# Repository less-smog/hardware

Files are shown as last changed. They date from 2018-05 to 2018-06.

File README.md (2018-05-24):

# IMPORTANT NOTE

The current revision (rev2) is undergoing tests - it's best to wait until the hardware has been well-tested before ordering PCBs and such.

# Open Hardware Air Pollution sensor

## housing
KRADEX Z56JPH housing is selected. Drawings and  3D models are available at [manufacturers site](https://www.kradex.com.pl/shop?product=z56).

## 3D model
Models from KiCad 4.0.7 release are used where available. Other models are in \lib\packages3d\ directory. You must copy them to KiCad KISYS3DMOD directory (i.e. C:\Program Files\KiCad\share\kicad\modules\packages3d on Windows). These models are:

* ESP-12E by [Jerry Dunmire (jdunmire)](https://github.com/jdunmire/kicad-ESP8266) (under Creative Commons Attribution-ShareAlike 4.0 International License)
* Molex 530470810, 530480810, 1050170001 by [Molex](https://www.molex.com/)
* MicroswitchSmd_4.3 by [Würth Elektronik](http://katalog.we-online.com/en/em/TASV_6X6_SMD?sid=3e9e02d6c0)
* Other are custom made

## LICENSE

This design has been released under the CERN Open Hardware Licence v1.2. We require that you notify us when you undertake either mass-production
of this design, or incorporate this design into an existing product, by e-mailing us at product@less-smog.org

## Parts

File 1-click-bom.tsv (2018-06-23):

References | Qty | Description
C1, C3 | 2 | C N.C. 0805 M
C6, C7, C8 | 3 | C 100nF 0603 M
C2, C3, C5, C9 | 4 | C 10uF/10V 0805 M
CON1 | 1 | USB OTG Micro Micro-B Molex-105017-0001
CON2 | 1 | Conn 01x05 PROG Pin Header Straight 1x05 Pitch2.54mm
CON3 | 1 | Jack-DC N.C. BARREL JACK
CON4 | 1 | Conn 01x04 HTU21D module
CON5 | 1 | Conn 01x08 PMS3003/5003 Molex PicoBlade 53048-0810
CON6 | 1 | Conn 01x07 AUX E45-TTL-1W
CON7 | 1 | Conn 01x05 SDS011 B5B-XH-A(LF)(SN)
D1, D2, D3, D4, D5, D6, D7, D8, D9, D10 | 10 | LED RABG RGB 5mm D5.0mm-4
Q1, Q2, Q3 | 3 | Q NMOS GSD BSS214N SOT-23
R9, R11, R12, R14 | 4 | R N.C. 0603 M
R39, R41 | 2 | R 10k 0603 M
RN1, RN2, RN3, RN4, RN5, RN6, RN7, RN8, RN9, RN10 | 10 | R Network 4 150R 4x0603 M
RN11, RN12 | 2 | R Network 4 10k 4x0603 M
SW1 | 1 | SW Push RESET MicroswitchSmd-4.3 N
SW2 | 1 | SW Push CFG MicroswitchSmd-4.3 N
TP1 | 1 | TEST 1P ESP PD TP 1.0 0.5 THT
TP2, TP14 | 2 | TEST 1P GND TP 1.7 1.0 THT
TP4 | 1 | TEST 1P CFG TP 1.7 1.0 THT
TP5 | 1 | TEST 1P RESET TP 1.7 1.0 THT
TP8 | 1 | TEST 1P +5V TP 1.0 0.5 THT
TP9 | 1 | TEST 1P +12V TP 1.0 0.5 THT
TP3, TP6, TP7, TP10, TP11, TP12 | 6 | TEST 1P - TP 1.0 0.5 THT
TP13 | 1 | TEST 1P +3V3 TP 1.0 0.5 THT
U1 | 1 | LM7805 TO220 N.C. 5V DC
U2 | 1 | TLV1117-33 TLV1117LV33DCY SOT-223-3Lead TabPin2
U3 | 1 | ESP-12E ESP-12F
U4 | 1 | HTU21D
U5 | 1 | PMS7003 THT

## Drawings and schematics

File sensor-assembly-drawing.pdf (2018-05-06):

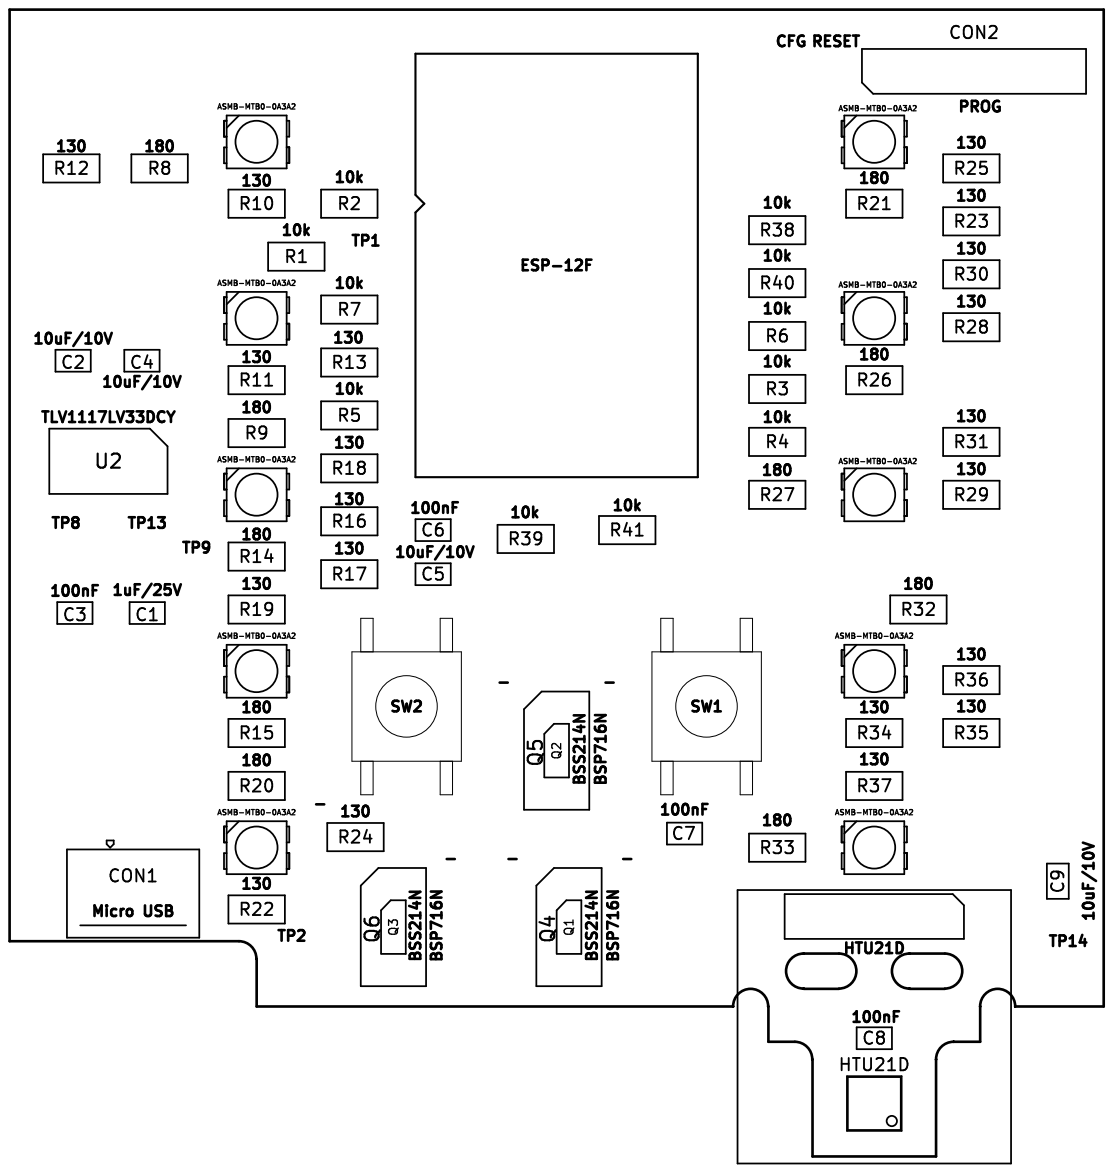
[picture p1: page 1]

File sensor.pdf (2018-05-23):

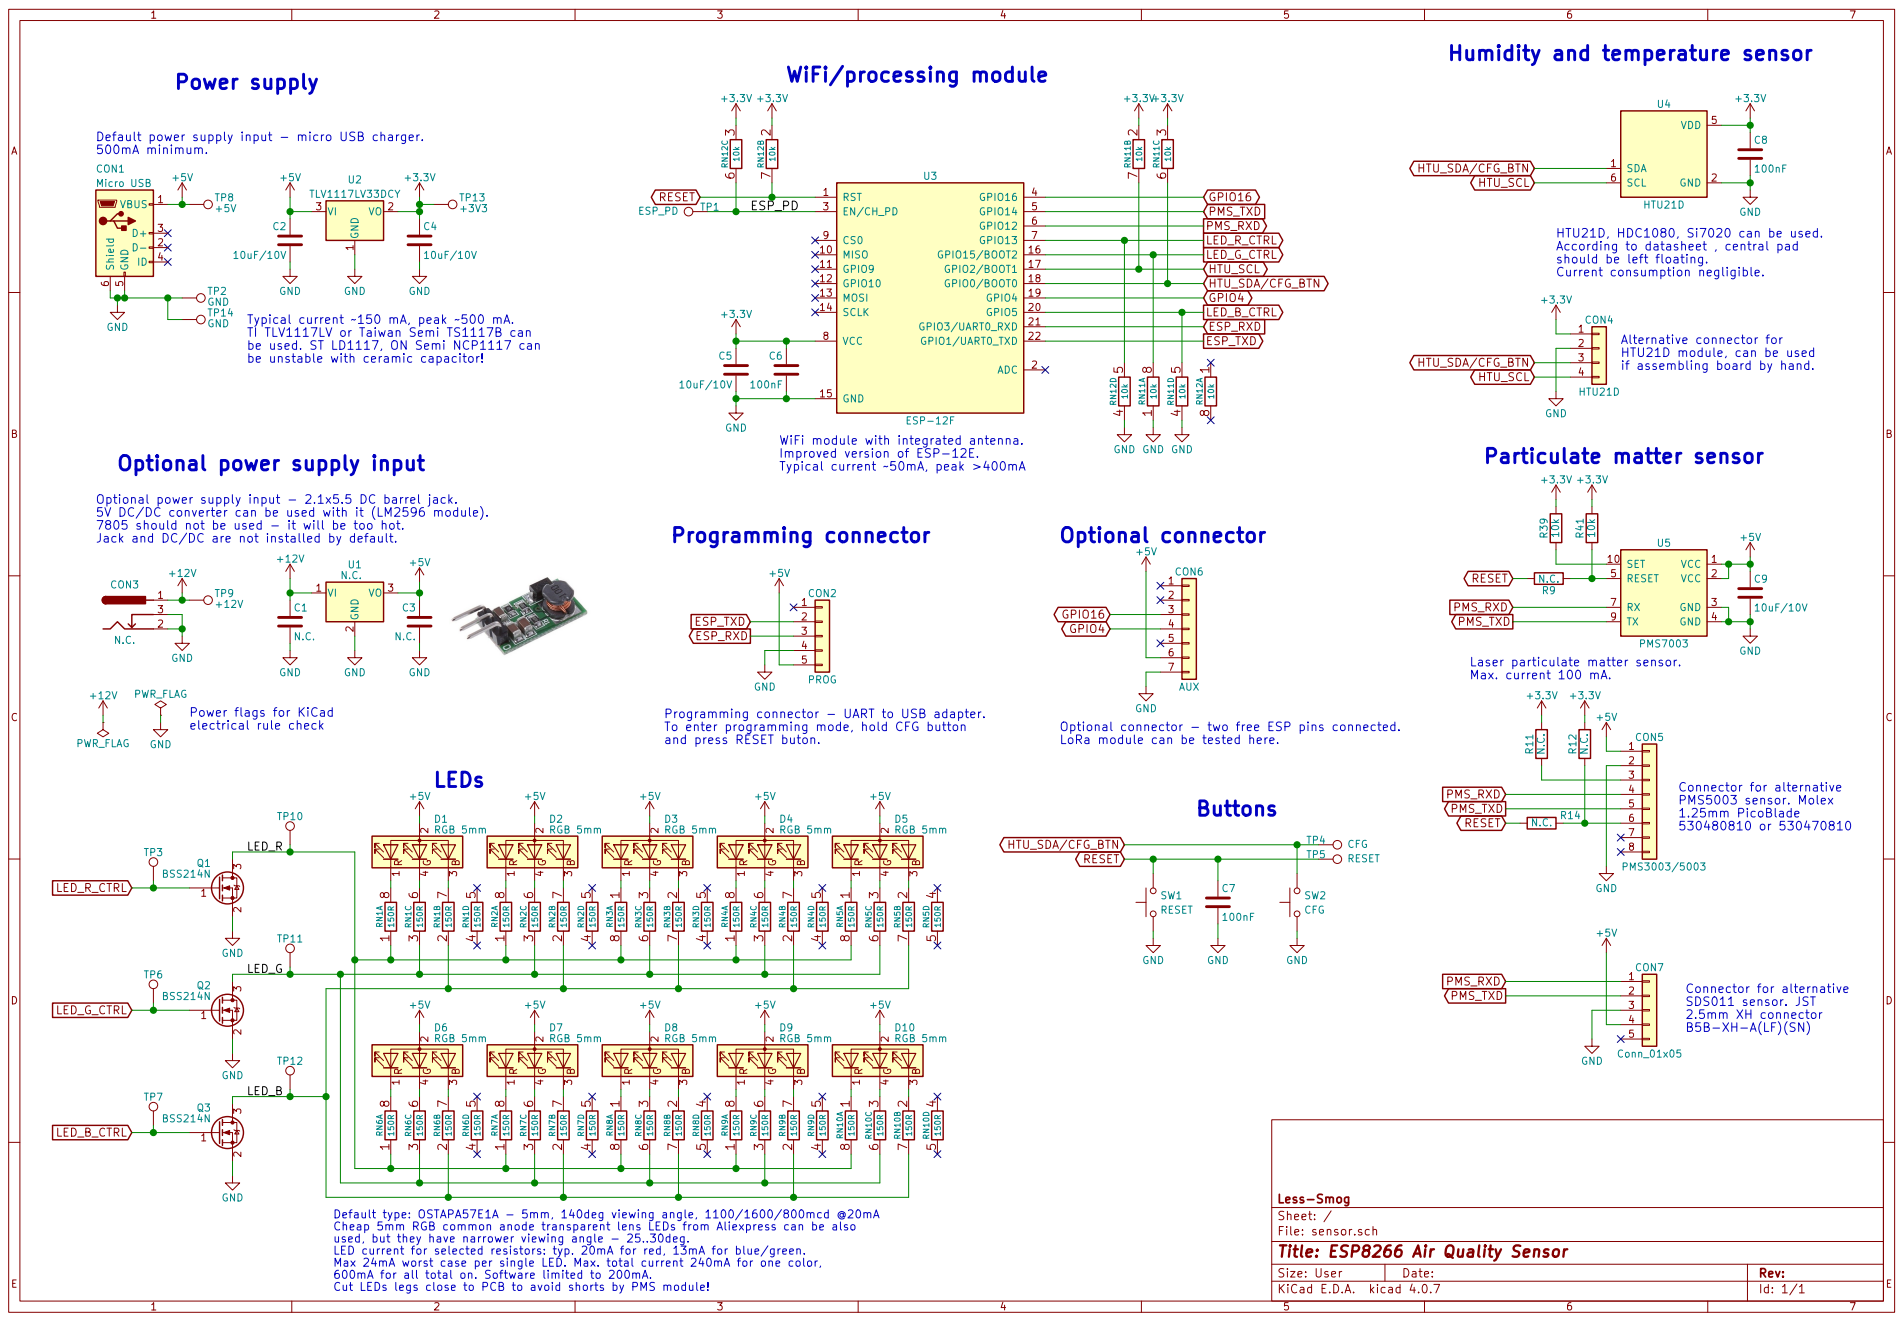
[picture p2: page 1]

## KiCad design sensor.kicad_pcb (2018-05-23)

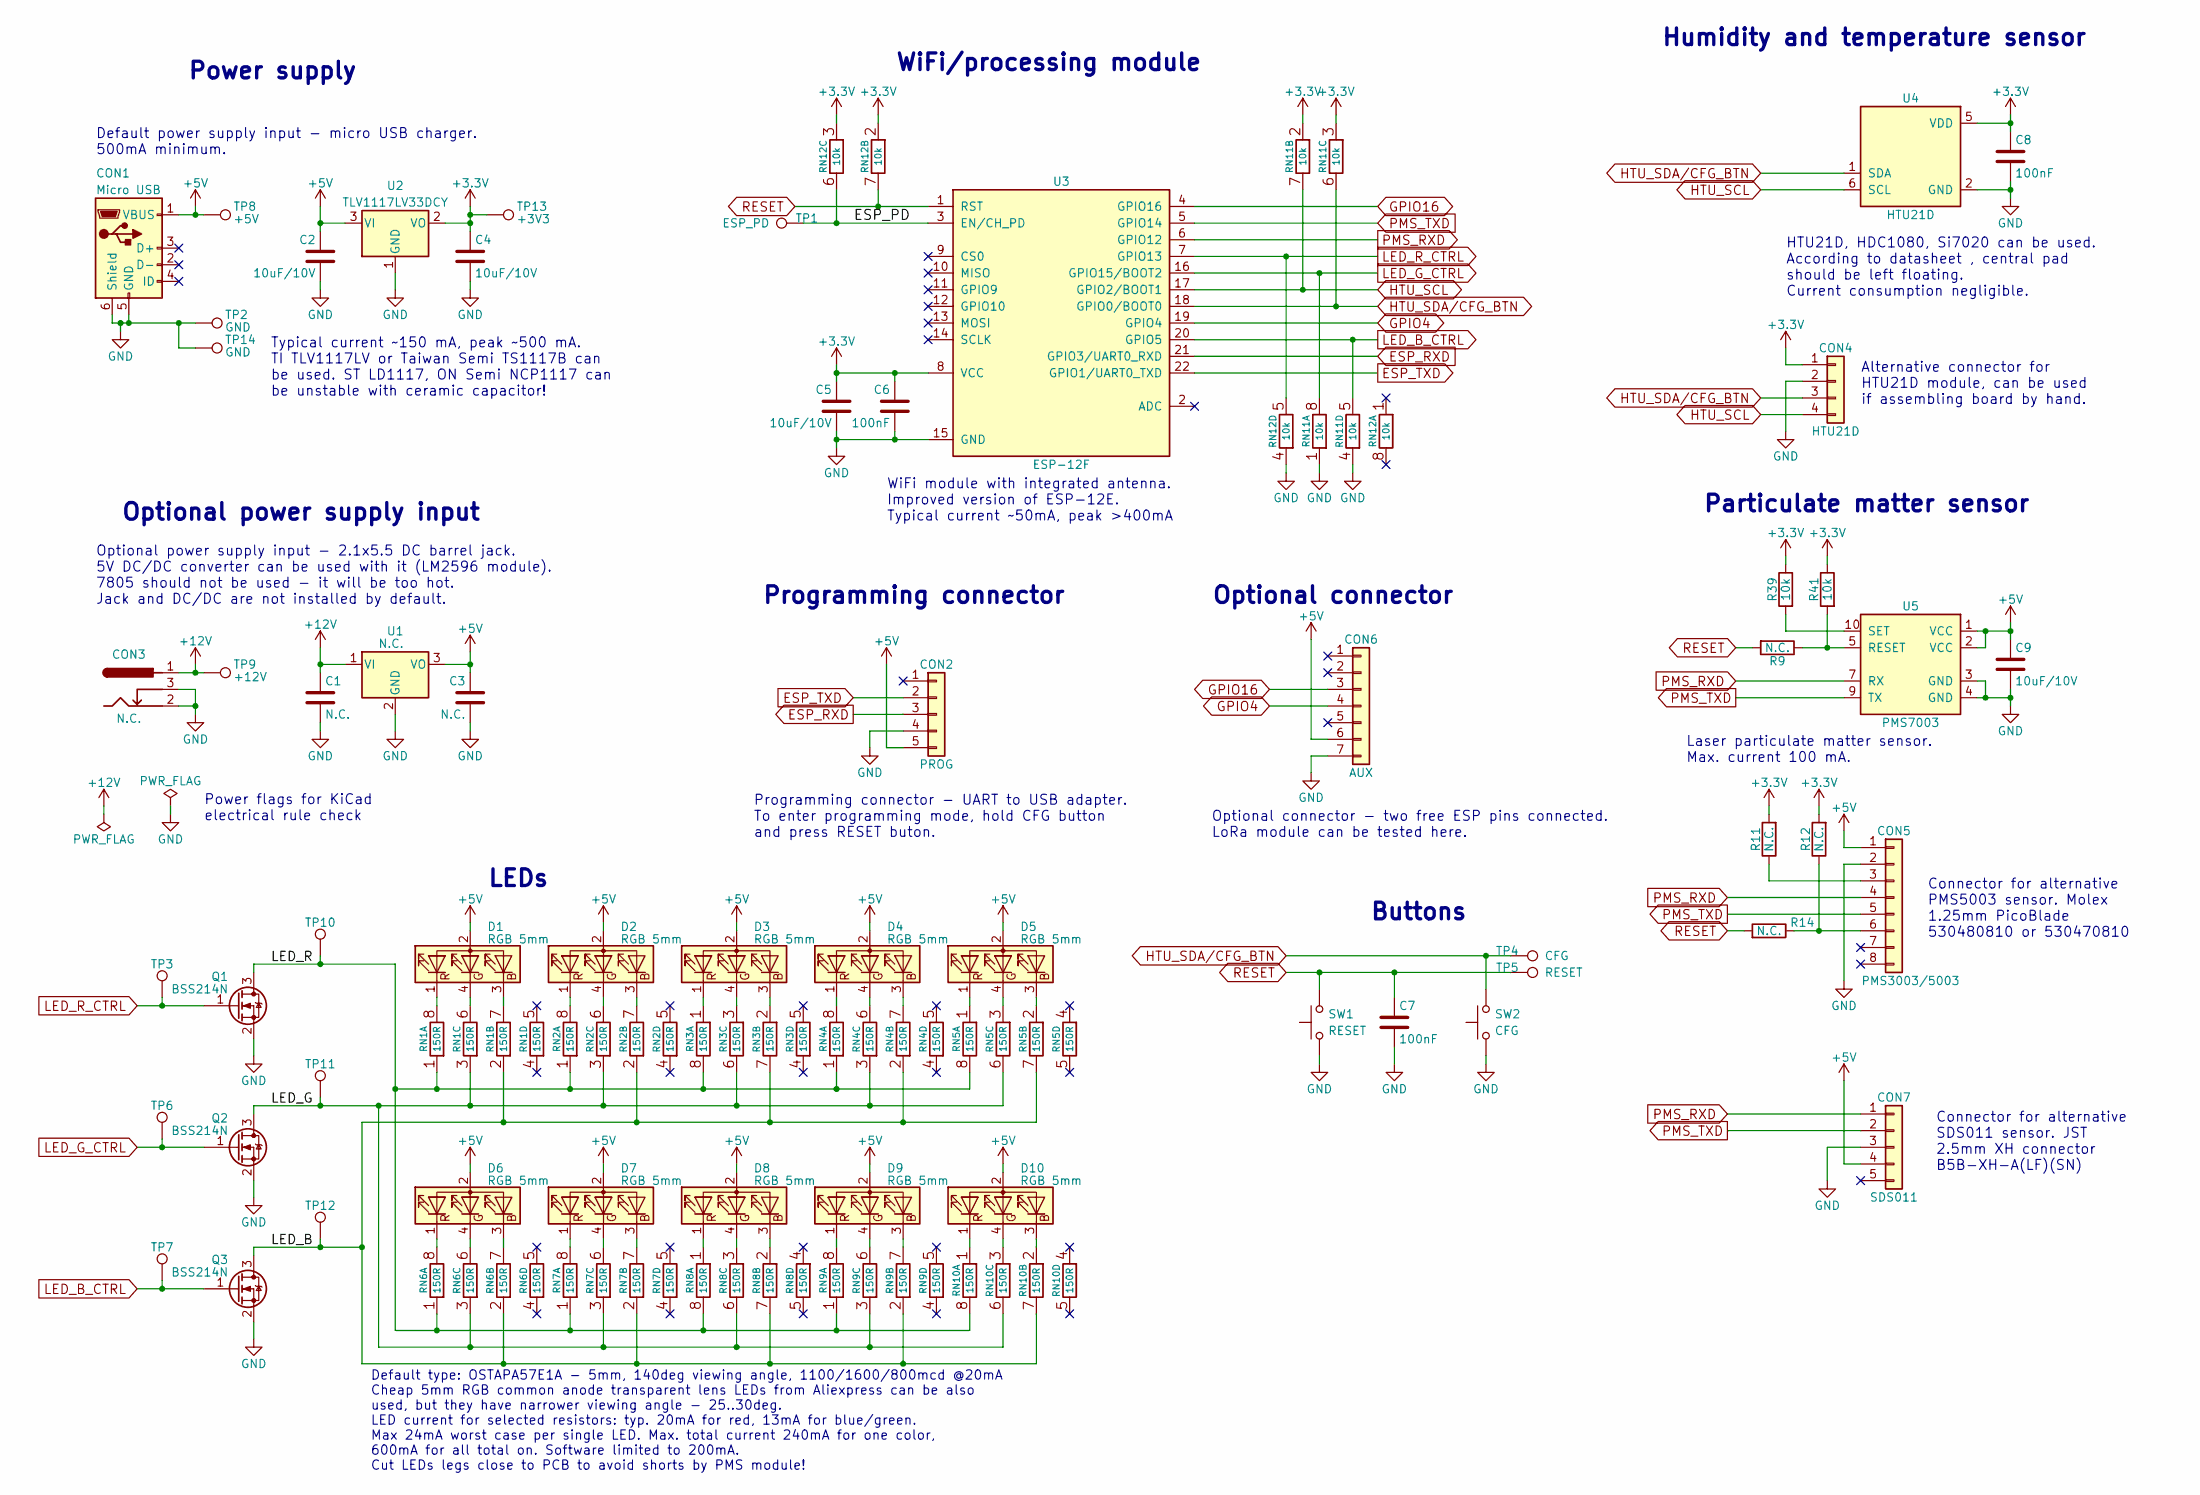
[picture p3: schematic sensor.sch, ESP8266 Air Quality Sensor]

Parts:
C1, C3: N.C.; 0805_M
C2, C4, C5, C9: 10uF/10V; 0805_M
C6, C7, C8: 100nF; 0603_M
CON1: Micro USB; USB_Micro-B_Molex-105017-0001
CON2: PROG; Pin_Header_Straight_1x05_Pitch2.54mm
CON3: N.C.; BARREL_JACK
CON4: HTU21D; HTU21D_module
CON5: PMS3003/5003; Molex_PicoBlade_53048-0810
CON6: AUX; E45-TTL-1W
CON7: SDS011; B5B-XH-A(LF)(SN)
D1, D2, D3, D4, D5, D6, D7, D8, D9, D10: RGB 5mm; LED_D5.0mm-4
Q1, Q2, Q3: BSS214N; SOT-23
R9, R11, R12, R14: N.C.; 0603_R_M
R39, R41: 10k; 0603_R_M
RN1, RN2, RN3, RN4, RN5, RN6, RN7, RN8, RN9, RN10: 150R; 4x0603_M
RN11, RN12: 10k; 4x0603_M
SW1: RESET; MicroswitchSmd-4.3_N
SW2: CFG; MicroswitchSmd-4.3_N
TP1: ESP_PD; TP_1.0_0.5_THT
TP2, TP14: GND; TP_1.7_1.0_THT
TP3, TP6, TP7, TP10, TP11, TP12: -; TP_1.0_0.5_THT
TP4: CFG; TP_1.7_1.0_THT
TP5: RESET; TP_1.7_1.0_THT
TP8: +5V; TP_1.0_0.5_THT
TP9: +12V; TP_1.0_0.5_THT
TP13: +3V3; TP_1.0_0.5_THT
U1: N.C.; 5V_DC_DC
U2: TLV1117LV33DCY; SOT-223-3Lead_TabPin2
U3: ESP-12F
U4: HTU21D
U5: PMS7003; PMS7003_THT

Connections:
+3V3: C4.1, C5.1, C6.1, C8.1, CON4.1, R11.2, R12.2, R39.1, R41.1, RN11.2 (1), RN11.3 (1), RN12.2 (1), RN12.3 (1), TP13.1, U2.2 (VO), U3.8 (VCC), U4.5 (VDD)
+5V: C2.1, C3.1, C9.1, CON1.1 (VBUS), CON2.5, CON5.1, CON6.6, CON7.4, D1.2 (A), D2.2 (A), D3.2 (A), D4.2 (A), D5.2 (A), D6.2 (A), D7.2 (A), D8.2 (A), D9.2 (A), D10.2 (A), TP8.1, U1.3 (VO), U2.3 (VI), U5.1 (VCC), U5.2 (VCC)
+12V: C1.1, CON3.1, TP9.1, U1.1 (VI)
/ESP_PD: RN12.6 (2), TP1.1, U3.3 (EN/CH_PD)
/LED_B: Q3.3 (D), RN1.2 (1), RN2.2 (1), RN3.7 (2), RN4.2 (1), RN5.7 (2), RN6.2 (1), RN7.2 (1), RN8.7 (2), RN9.2 (1), RN10.7 (2), TP12.1
/LED_G: Q2.3 (D), RN1.3 (1), RN2.3 (1), RN3.6 (2), RN4.3 (1), RN5.6 (2), RN6.3 (1), RN7.3 (1), RN8.6 (2), RN9.3 (1), RN10.6 (2), TP11.1
/LED_R: Q1.3 (D), RN1.1, RN2.1, RN3.8 (2), RN4.1, RN5.8 (2), RN6.1, RN7.1, RN8.8 (2), RN9.1, RN10.8 (2), TP10.1
ESP_RXD: CON2.3, U3.21 (GPIO3/UART0_RXD)
ESP_TXD: CON2.2, U3.22 (GPIO1/UART0_TXD)
GND: C1.2, C2.2, C3.2, C4.2, C5.2, C6.2, C7.2, C8.2, C9.2, CON1.5 (GND), CON1.6 (Shield), CON2.4, CON3.2, CON3.3, CON4.2, CON5.2, CON6.7, CON7.3, Q1.2 (S), Q2.2 (S), Q3.2 (S), RN11.1, RN11.4 (1), RN12.4 (1), SW1.2, SW2.2, TP2.1, TP14.1, U1.2 (GND), U2.1 (GND), U3.15 (GND), U4.2 (GND), U5.3 (GND), U5.4 (GND)
GPIO4: CON6.4, U3.19 (GPIO4)
GPIO16: CON6.3, U3.4 (GPIO16)
HTU_SCL: CON4.4, RN11.7 (2), U3.17 (GPIO2/BOOT1), U4.6 (SCL)
HTU_SDA/CFG_BTN: CON4.3, RN11.6 (2), SW2.1, TP4.1, U3.18 (GPIO0/BOOT0), U4.1 (SDA)
LED_B_CTRL: Q3.1 (G), RN11.5 (2), TP7.1, U3.20 (GPIO5)
LED_G_CTRL: Q2.1 (G), RN11.8 (2), TP6.1, U3.16 (GPIO15/BOOT2)
LED_R_CTRL: Q1.1 (G), RN12.5 (2), TP3.1, U3.7 (GPIO13)
unnamed: CON5.3, R11.1
unnamed: CON5.6, R12.1, R14.1
unnamed: D1.1 (RK), RN1.8 (2)
unnamed: D1.3 (BK), RN1.7 (2)
unnamed: D1.4 (GK), RN1.6 (2)
unnamed: D2.1 (RK), RN2.8 (2)
unnamed: D2.3 (BK), RN2.7 (2)
unnamed: D2.4 (GK), RN2.6 (2)
unnamed: D3.1 (RK), RN3.1
unnamed: D3.3 (BK), RN3.2 (1)
unnamed: D3.4 (GK), RN3.3 (1)
unnamed: D4.1 (RK), RN4.8 (2)
unnamed: D4.3 (BK), RN4.7 (2)
unnamed: D4.4 (GK), RN4.6 (2)
unnamed: D5.1 (RK), RN5.1
unnamed: D5.3 (BK), RN5.2 (1)
unnamed: D5.4 (GK), RN5.3 (1)
unnamed: D6.1 (RK), RN6.8 (2)
unnamed: D6.3 (BK), RN6.7 (2)
unnamed: D6.4 (GK), RN6.6 (2)
unnamed: D7.1 (RK), RN7.8 (2)
unnamed: D7.3 (BK), RN7.7 (2)
unnamed: D7.4 (GK), RN7.6 (2)
unnamed: D8.1 (RK), RN8.1
unnamed: D8.3 (BK), RN8.2 (1)
unnamed: D8.4 (GK), RN8.3 (1)
unnamed: D9.1 (RK), RN9.8 (2)
unnamed: D9.3 (BK), RN9.7 (2)
unnamed: D9.4 (GK), RN9.6 (2)
unnamed: D10.1 (RK), RN10.1
unnamed: D10.3 (BK), RN10.2 (1)
unnamed: D10.4 (GK), RN10.3 (1)
unnamed: R39.2, U5.10 (SET)
unnamed: R9.1, R41.2, U5.5 (RESET)
PMS_RXD: CON5.4, CON7.1, U3.6 (GPIO12), U5.7 (RX)
PMS_TXD: CON5.5, CON7.2, U3.5 (GPIO14), U5.9 (TX)
RESET: C7.1, R9.2, R14.2, RN12.7 (2), SW1.1, TP5.1, U3.1 (RST)

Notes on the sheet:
WiFi module with integrated antenna. Improved version of ESP-12E. Typical current ~~50mA, peak >400mA
HTU21D, HDC1080, Si7020 can be used. According to datasheet , central pad should be left floating. Current consumption negligible.
Laser particulate matter sensor. Max. current 100 mA.
Default type: OSTAPA57E1A - 5mm, 140deg viewing angle, 1100/1600/800mcd @20mA Cheap 5mm RGB common anode transparent lens LEDs from Aliexpress can be also used, but they have narrower viewing angle - 25..30deg. LED current for selected resistors: typ. 20mA for red, 13mA for blue/green. Max 24mA wor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
Typical current ~~150 mA, peak ~~500 mA. TI TLV1117LV or Taiwan Semi TS1117B can be used. ST LD1117, ON Semi NCP1117 can be unstable with ceramic capacitor!
Optional power supply input - 2.1x5.5 DC barrel jack. 5V DC/DC converter can be used with it (LM2596 module). 7805 should not be used - it will be too hot. Jack and DC/DC are not installed by default.
Default power supply input - micro USB charger. 500mA minimum.
Programming connector - UART to USB adapter. To enter programming mode, hold CFG button and press RESET buton.
Alternative connector for HTU21D module, can be used if assembling board by hand.
Humidity and temperature sensor
Particulate matter sensor
Connector for alternative PMS5003 sensor. Molex 1.25mm PicoBlade 530480810 or 530470810
Buttons
LEDs
WiFi/processing module
Programming connector
Power supply
Optional power supply input
Power flags for KiCad electrical rule check
Optional connector
Optional connector - two free ESP pins connected. LoRa module can be tested here.
Connector for alternative SDS011 sensor. JST 2.5mm XH connector B5B-XH-A(LF)(SN)

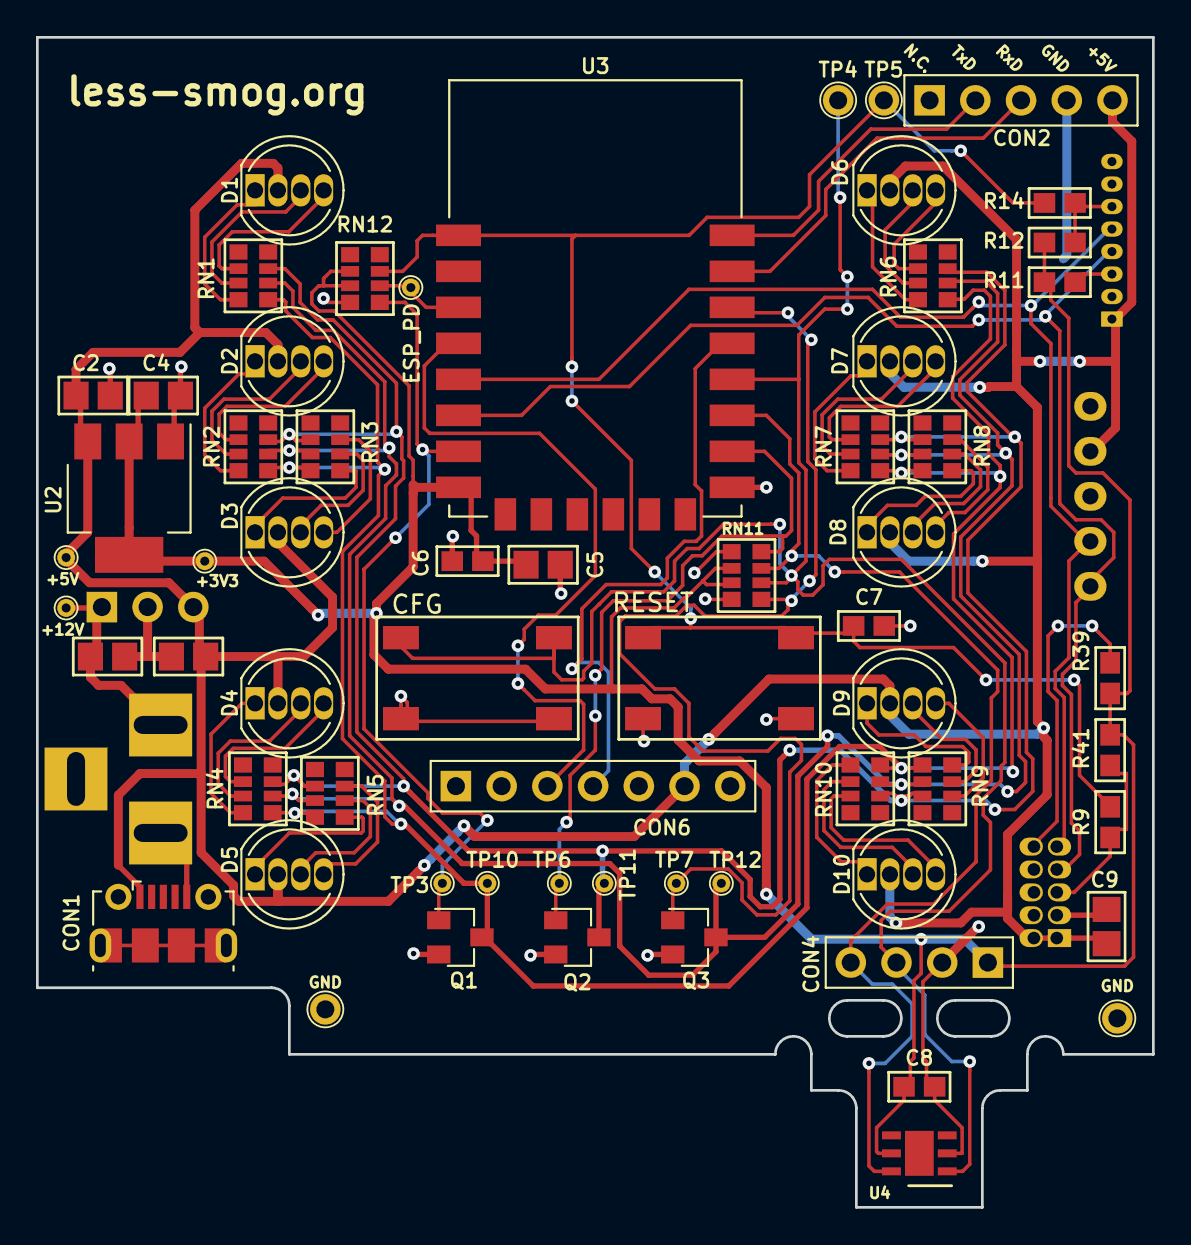
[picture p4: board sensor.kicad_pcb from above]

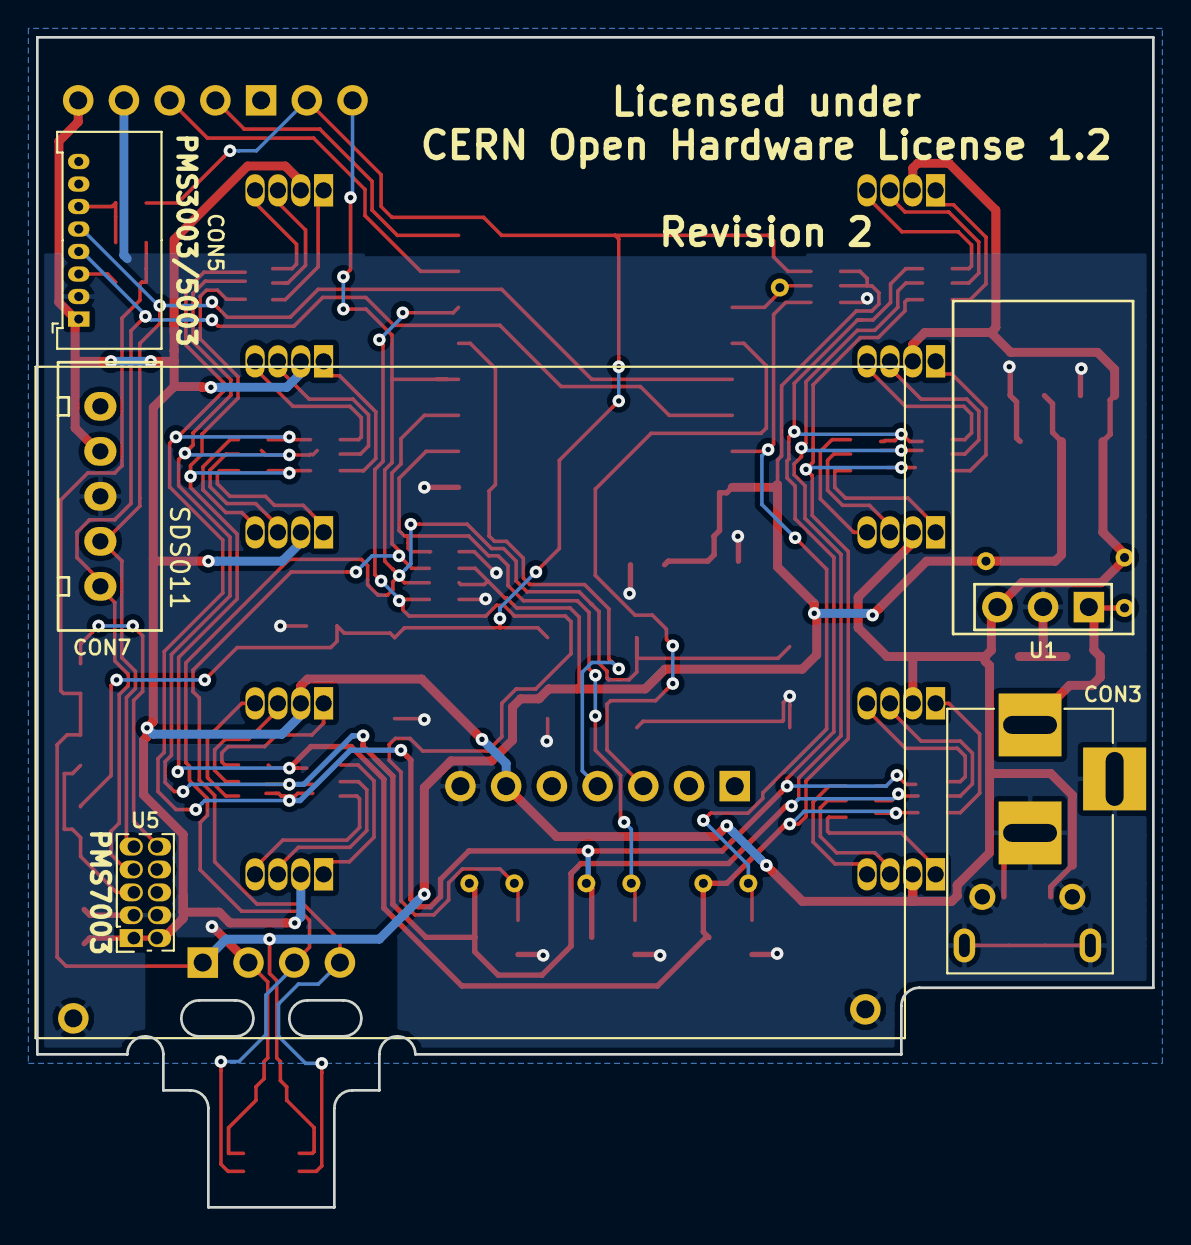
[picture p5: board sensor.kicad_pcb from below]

Board: 2 copper layers, 62.0 x 65.0 mm, 68 parts (5 on the bottom side), 54 nets.

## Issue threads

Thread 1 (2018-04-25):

GPIO16 can't be driven in PWM mode

jasiek, 2018-04-25:
This library (https://github.com/StefanBruens/ESP8266_new_pwm) permits us to drive three LEDs via PWM to get an entire palette of colours. The library in question won't let us use GPIO16, which in revision 1 is connected to the blue LED driver.

Potential solutions:
* use a different GPIO
* use a hardware PWM driver (I2C), this has the nice benefit of freeing up pins as we can share the I2C bus with temp+humidity sensor.
* tweak the library to support GPIO16
* use a different library
* use ESP32 instead

jasiek, 2018-04-25:
Additionally, the library in question will exhibit blinking when maskable interrupts are used. This is a minor problem.

jasiek, 2018-04-25:
Potential drivers:

* [ON Semiconductor NCP5623DTBR2G, LED Driver 3-Segments, 2.7 → 5.5 V, 14-Pin TSSOP
](https://uk.rs-online.com/web/p/led-display-drivers/7922112/)
* [NXP PCA9633DP2,118, LED Driver 4-Segments, 2.5 V, 3.3 V, 5 V, 10-Pin TSSOP](https://uk.rs-online.com/web/p/led-display-drivers/0510908/)
* [NXP PCA9553DP/01,118, LED Driver 4-Segments, 2.5 V, 3.3 V, 5 V, 8-Pin TSSOP](https://uk.rs-online.com/web/p/led-display-drivers/1661600/)
* [WORLDSEMI WS2818A
Driver; PWM controller; kontroler LED; 0,0165A; 7V; Kanały:3](https://www.tme.eu/pl/details/ws2818a/drivery-led/worldsemi/) - Not I2C

Cost: GBP 0.2 - 1.10

jasiek, 2018-05-02:
So I think we've settled on rewiring this per this post: https://hackaday.io/project/147459-less-smogorg/log/145648-slight-rewiring-required-to-get-pwm-to-work

Closed 2018-05-22.

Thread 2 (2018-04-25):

Use array chip resistors instead

jasiek, 2018-04-25:
Problem: We have a ton of resistors on the board and we could use some free space.

Closed 2018-05-22.

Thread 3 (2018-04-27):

Optional 5V regulator is too hot at 12V

NiceCircuits, 2018-04-27:
When optional 5V regulator is used and 12V power supply is connected, 7805 temperature reaches >90*C.
Proposed solution: use 5V DC/DC converter module, like this one:
https://www.ebay.com/itm/5W-9V-12V-24V-To-5V-DC-DC-Step-Down-Converter-Module-Replace-TO-220-7805-LM2596/222641567186

jasiek, 2018-04-27:
This is a drop-in replacement, right?

NiceCircuits, 2018-05-01:
Yes, but I would like to check if it will fit on the PCB without problems and remove 7805 from documentation to discourage anyone from using it ;)

NiceCircuits, 2018-05-01:
Another options:
https://www.ebay.com/itm/DC-DC-7V-28V-9V-12V-To-DC-5V-3A-DC-DC-Step-down-Buck-Conveter-Module-Chip-Tools/222913561934
https://www.ebay.com/itm/3A-5v-9V-12v-To-3-3v-5v-DC-DC-Buck-Step-down-Power-Supply-Converter-Module/173273469891
but only versions without regulation by potentiometer. With regulated, somebody will almost certainly set invalid voltage and cook the board ;)

jasiek, 2018-05-02:
This is an optional component anyway - let's just make sure that the DD4012SB_5V fits on the board and be done with it.

Closed 2018-05-22.

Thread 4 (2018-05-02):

Replace current SMD LEDs with THT variants

jasiek, 2018-05-02:
Given we'd like these to be assembled by students, etc - I think it makes sense to pre-assemble the SMD components and leave a few ones which are easy to solder by hand as an exercise. I'd like us to replace the LEDs with THT variants - those should be cheaper anyway.

Let's try and pick something which is widely available.

NiceCircuits, 2018-05-20:
We need common anode version. Wider angle will also be better (60deg or more). Proposed:
https://www.tme.eu/en/details/ostapa57e1a/tht-leds-5mm/optosupply/ £0.185/pcs @100pcs.

We can also try some cheap AliExpress LEDs, but they are all 25-30deg - maybe that will be enough?
https://www.aliexpress.com/item/Hot-100-pcs-5mm-4-pin-RGB-LED-Common-Anode-Red-Green-Blue/32830737328.html

jasiek, 2018-05-20:
The LEDs I got from China are 25 degrees, and they seem fine. Keep in mind
that the transparent part of the case will diffuse the light quite a lot.

I'm more concerned about the Red channel operating at a different voltage
compared to green and blue. Are these consistent enough throughout 5mm LEDs
that we can just assume this is a constant across all potential LEDs?

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

NiceCircuits, 2018-05-20:
Yes, it's common that red LEDs have ~2V voltage drop and bright green and blue ~3V. I don't expect other case.

Closed 2018-05-22.

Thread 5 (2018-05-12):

There is too much solder paste on micro USB connector pads

NiceCircuits, 2018-05-12:
There is too much solder paste - on half of reflow soldered boards pads were shorted.
Designed solder paste stencil openings are 0.2x1.15mm. In real stencil, openings are 0.3..0.35mm wide. It looks like all openings are 0.1mm wider than designed, probably due to laser cutting process.

Closed 2018-05-23.

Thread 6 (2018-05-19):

Is it possible to hook up an SX1276 LoRa module as an add-on given how many pins we have?

jasiek, 2018-05-19:
https://www.aliexpress.com/item/2pcs-868MHz-super-low-power-RF-LoRa-module-SX1276-chip-Long-Distance-communication-Receiver-and-Transmitter/32859550198.html - let's see if we have enough pins left to be able to add this board as an add-on.

NiceCircuits, 2018-05-21:
After pinout consolidation, we have two I/O left. More will be available if programming/debug UART is merged with PMS UART, but it will make debug harder - will not be implemented in this version.
For testing, we can connect another kind of LoRa module with UART communication. I will break out the two free pins to headers.
https://pl.aliexpress.com/item/Free-shipping-2pics-CDSENET-E45-TTL-100-20dBm-3km-SX1276-868MHz-LoRa-RF-Transceiver-Module/32791688505.html

jasiek, 2018-05-21:
👍

Closed 2018-05-22.

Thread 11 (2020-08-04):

Missing software

kenokenobingo, 2020-08-04:
I’ve built rev 2 of this board, but can’t find any software for it. The GitHub repo is acutally only a skeleton project: https://github.com/less-smog/software.

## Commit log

2018-02-17 Initial commit of KiCad libraries
2018-02-17 Initial commit of schematic and PCB
    [sensor.kicad_pcb, sensor.sch]
2018-02-18 Use libraries from KiCad 4.0.7 instead of new from KiCad GitHub.
    [sensor.sch]
2018-02-18 Working on connections
    [sensor.sch]
2018-02-18 Add power supplies and other connections.
    [sensor.sch]
2018-02-20 Change packages to bigger ones, simpler to assemble.
    [sensor.sch]
2018-02-20 Schematic finishing and cleanup.
    [sensor.kicad_pcb, sensor.sch]
2018-02-20 Fix ERC errors, add more testpoints.
    [sensor.sch]
2018-02-21 Initial draft PCB placement
    [sensor.kicad_pcb, sensor.sch]
2018-02-21 Change some footprint pads to bigger ones.
    [sensor.kicad_pcb, sensor.sch]
2018-02-23 Add HTU21D module footprint
    [sensor.kicad_pcb, sensor.sch]
2018-02-23 Routing in progress
    [sensor.kicad_pcb]
2018-02-24 Routed PCB, routing to be optimized
    [sensor.kicad_pcb]
2018-02-24 Change some footprints. Optimize routing.
    [sensor.kicad_pcb, sensor.sch]
2018-02-24 Add 3D models
    [sensor.kicad_pcb]
2018-02-24 Update 3D model
    [sensor.kicad_pcb]
2018-02-24 Update PDF schematic
2018-02-25 Clean-up silkscreen.
    [sensor.kicad_pcb]
2018-02-26 Update 3D model.
    [sensor.kicad_pcb]
2018-03-08 Added licensing information, Open Hardware logo, project URL, etc.
    [sensor.kicad_pcb]
2018-03-10 Made a few layers visible.
    [sensor.kicad_pcb]
2018-03-10 Generated gerbers for manufacturing.
    [sensor-B.Adhes.gbr, sensor-B.CrtYd.gbr, sensor-B.Cu.gbr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]
2018-03-10 Added 1 click bom.
    [1-click-bom.tsv]
2018-03-10 Added BOM.
    [1-click-bom.tsv]
2018-03-11 Remove old gerber files
    [sensor-B.Adhes.gbr, sensor-B.CrtYd.gbr, sensor-B.Cu.gbr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]
2018-03-11 Update PCB to for production: - change via drills to 0.3mm - update solder mask expansion - update paste mask expansion - generate gerber files
    [sensor-B.Cu.gbl, sensor-B.Mask.gbs, sensor-B.SilkS.gbo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]
2018-03-11 Add board and stencil dimensions
    [sensor.kicad_pcb]
2018-03-14 Update soldermask color for kitspace preview
2018-03-14 Clean BOM
    [1-click-bom.tsv]
2018-03-14 Update BOM: remove unneded connector, add TME column, remove Farnell RL endings
    [1-click-bom.tsv]
2018-03-14 Added missing TME part.
    [1-click-bom.tsv]
2018-05-06 Update assembly drawing and generate pdf. Fix alternative Q4..Q6 values.
    [sensor.kicad_pcb, sensor.sch]
2018-05-20 [#4] Change LEDs to 5mm THT on schematic.
    [sensor.kicad_pcb, sensor.sch]
2018-05-20 [#4] Change LEDs to 5mm THT on schematic. [#8] Remove bigger transistor packages from schematic
    [sensor.kicad_pcb, sensor.sch]
2018-05-20 [#2] Change LED resistors to chip arrays.
    [sensor.sch]
2018-05-20 Change ESP connections. [#6] Free hardware SPI for Lora module [#9] Disconnect PMS_SET and PMS_RESET Other connections are also moved. ESP programming serial port merged with PMS serial.
    [sensor.sch]
2018-05-21 Go back to previous ESP pinout, except I2C and LED_B_CTRL [#6] Hardware SPI for Lora module not available.
    [sensor.sch]
2018-05-21 [#5] Reduce solder paste on micro USB connector pads
    [sensor.kicad_pcb]
2018-05-21 Change components to smaller ones. [#2] Change resistors to chip arrays.
    [sensor.sch]
2018-05-21 [#3] Change optional 7805 to DC/DC
    [sensor.sch]
2018-05-21 Fix ERC errors
    [sensor.sch]
2018-05-22 Crudely routed board. Changed some footprints to easier to solder.
    [sensor.kicad_pcb, sensor.sch]
2018-05-22 Routing optimization
    [sensor.kicad_pcb]
2018-05-22 Button position correction
    [sensor.kicad_pcb]
2018-05-22 PDF schematic added
    [sensor.sch]
2018-05-23 Add connector for SDS011 Close #10
    [sensor.kicad_pcb, sensor.sch]
2018-05-23 [#10] Update schematic PDF. Add remaining library footprints.
    [sensor.sch]
2018-05-23 Update silkscreen
    [sensor.kicad_pcb, sensor.sch]
2018-05-23 Update Gerber files
    [sensor-B.Cu.gbl, sensor-B.Mask.gbs, sensor-B.SilkS.gbo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]
2018-05-24 Updated 1 click BOM.
    [1-click-bom.tsv]
2018-06-23 Sorted component references for easier assembly.
    [1-click-bom.tsv]

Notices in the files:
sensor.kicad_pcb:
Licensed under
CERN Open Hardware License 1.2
